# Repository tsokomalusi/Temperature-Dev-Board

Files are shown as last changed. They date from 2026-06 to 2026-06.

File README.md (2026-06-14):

# Project Requirements/Problem Statement
[Challenge](https://github.com/tsokomalusi/Temperature-Dev-Board/blob/main/%F0%9F%A7%A9%20Course%201%20%E2%80%94%20Temperature%20Monitor%20Dev%20Board%20-%20Course%201%20%E2%80%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)

# Temperature-Dev-Board

STM32-based temperature monitoring board featuring:

 10k NTC thermistor
- ADC temperature measurement
- OLED display
- USB power
- Expansion headers

## Hardware

- MCU: STM32
- Sensor: 10k NTC Thermistor
- Display: OLED
- 
## Schematic
The proposed schematic for this PCB Design challenge can be found within this repository
[Schematic](https://github.com/tsokomalusi/Temperature-Dev-Board/blob/main/Temperature_Monitoring_Dev_Board.pdf)

## Images

### BLOCK DIAGRAM
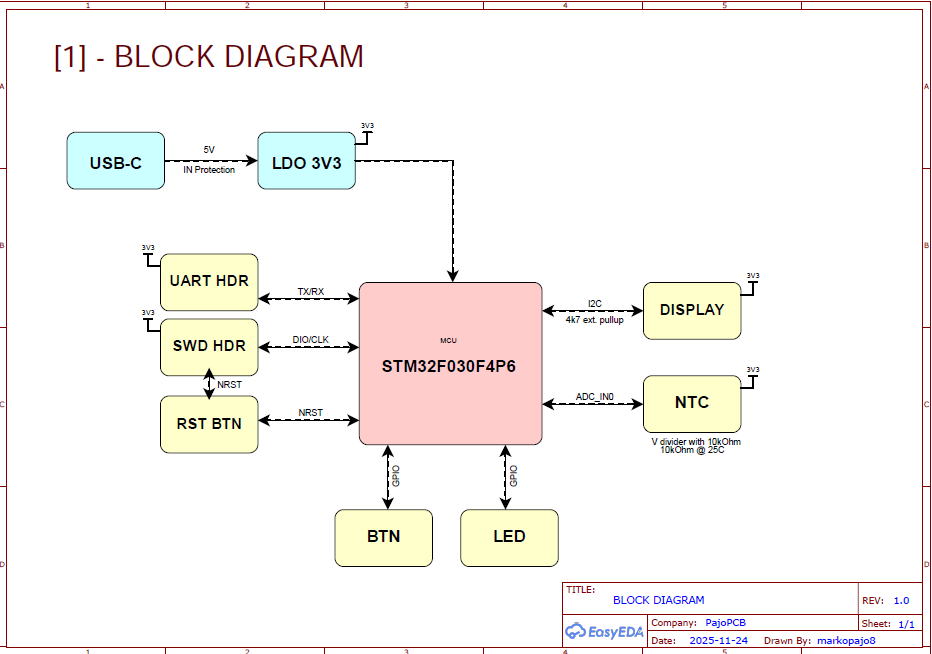
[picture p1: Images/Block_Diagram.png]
Block Diagram


### 3D MODEL (TOP & BOTTOM VIEW)

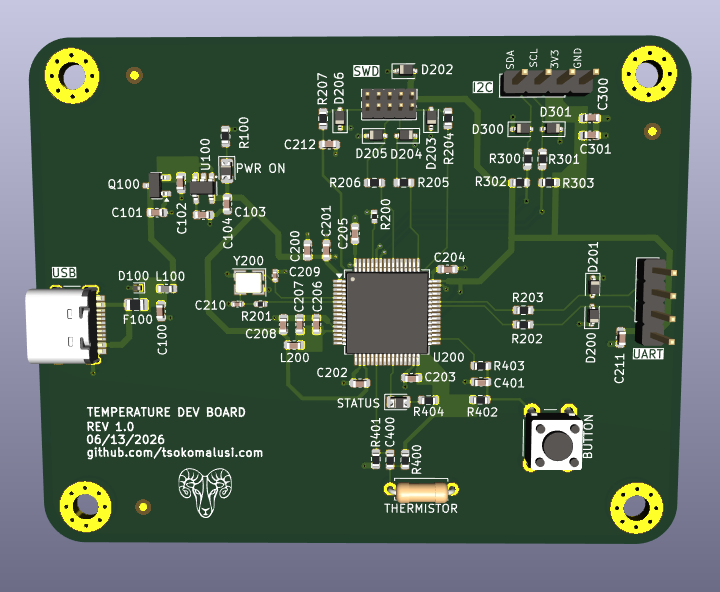
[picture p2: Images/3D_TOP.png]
3D TOP


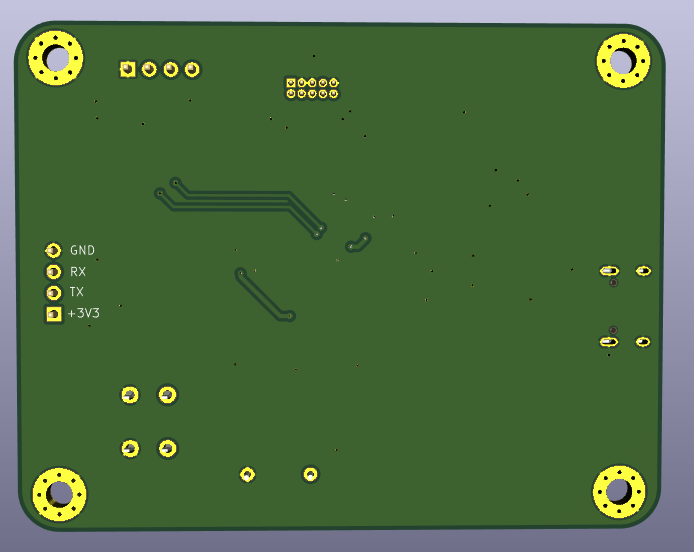
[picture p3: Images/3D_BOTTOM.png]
3D BOTTOM


### PCB LAYER (2 LAYER)

PCB STACKUP (2 LAYER)

L1: Signal/POWER
L2: GND

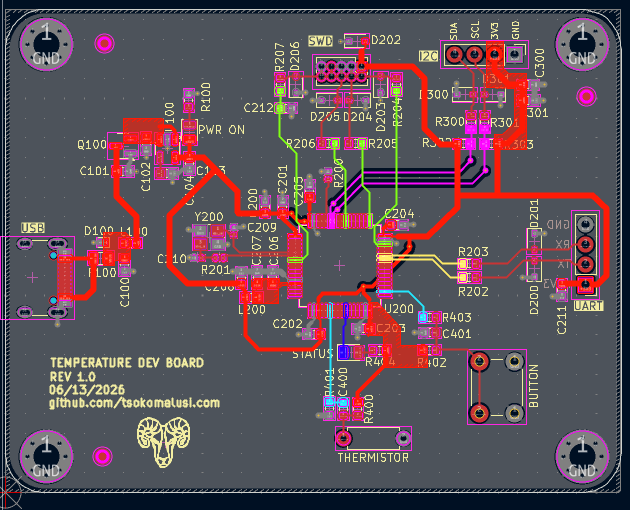
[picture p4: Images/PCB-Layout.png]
PCB_Layout


## Manufacturing

Gerber files are located in the manufacturing folder.

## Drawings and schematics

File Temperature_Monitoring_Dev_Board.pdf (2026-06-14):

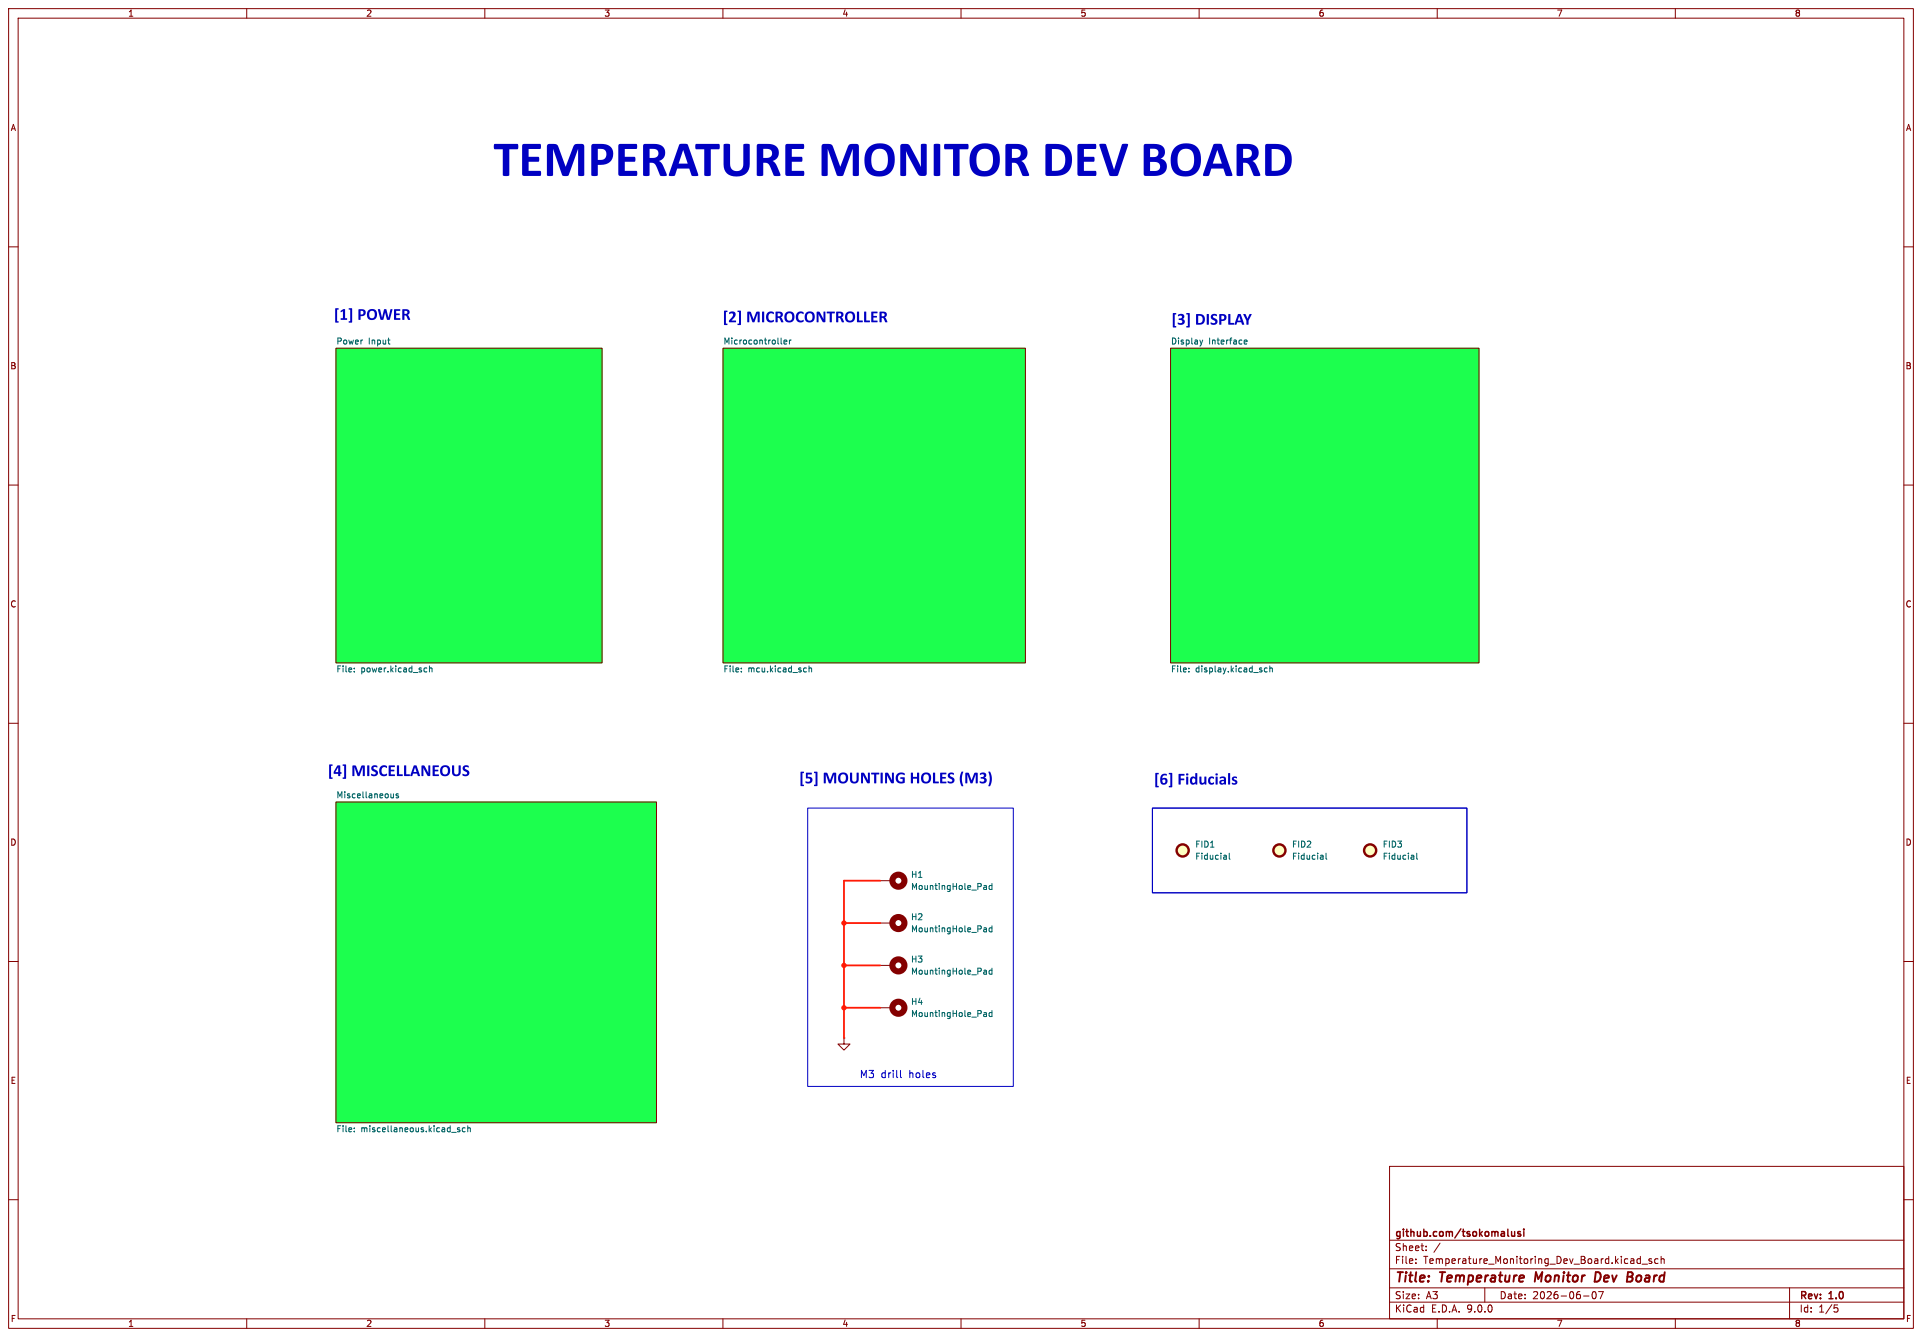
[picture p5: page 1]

Microcontroller File: mcu.kicad_sch Power Input File: power.kicad_sch

File: Temperature_Monitoring_Dev_Board.kicad_sch Sheet: / github.com/tsokomalusi Miscellaneous File: miscellaneous.kicad_sch

Id: 1/5 Title: Temperature Monitor Dev Board

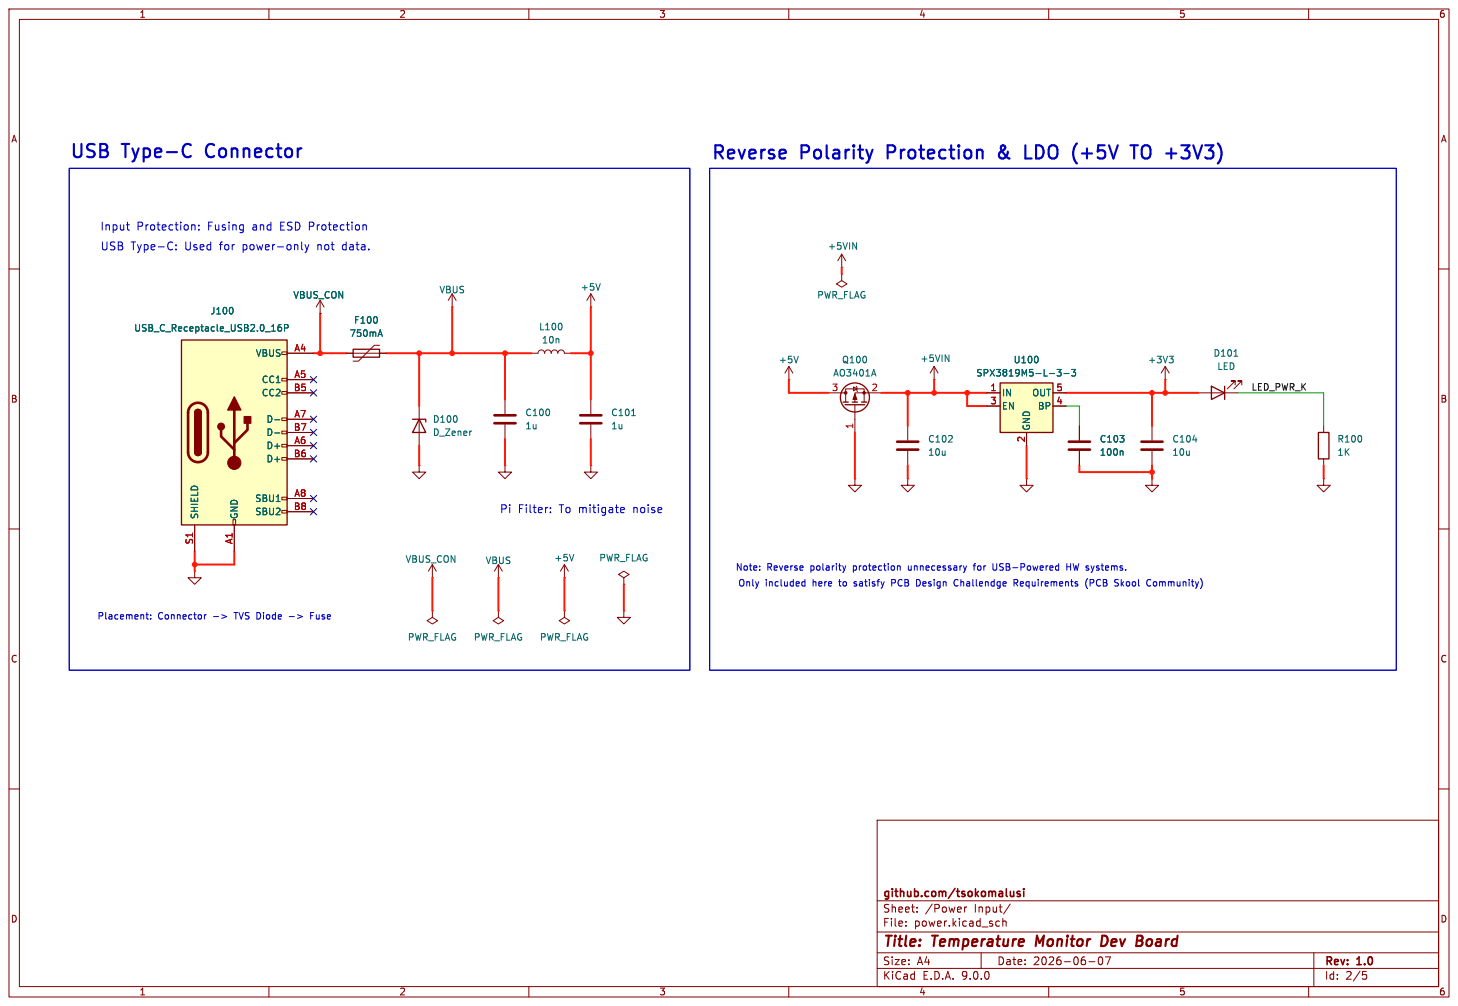
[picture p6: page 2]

Reverse Polarity Protection & LDO (+5V TO +3V3)

Id: 2/5 Title: Temperature Monitor Dev Board

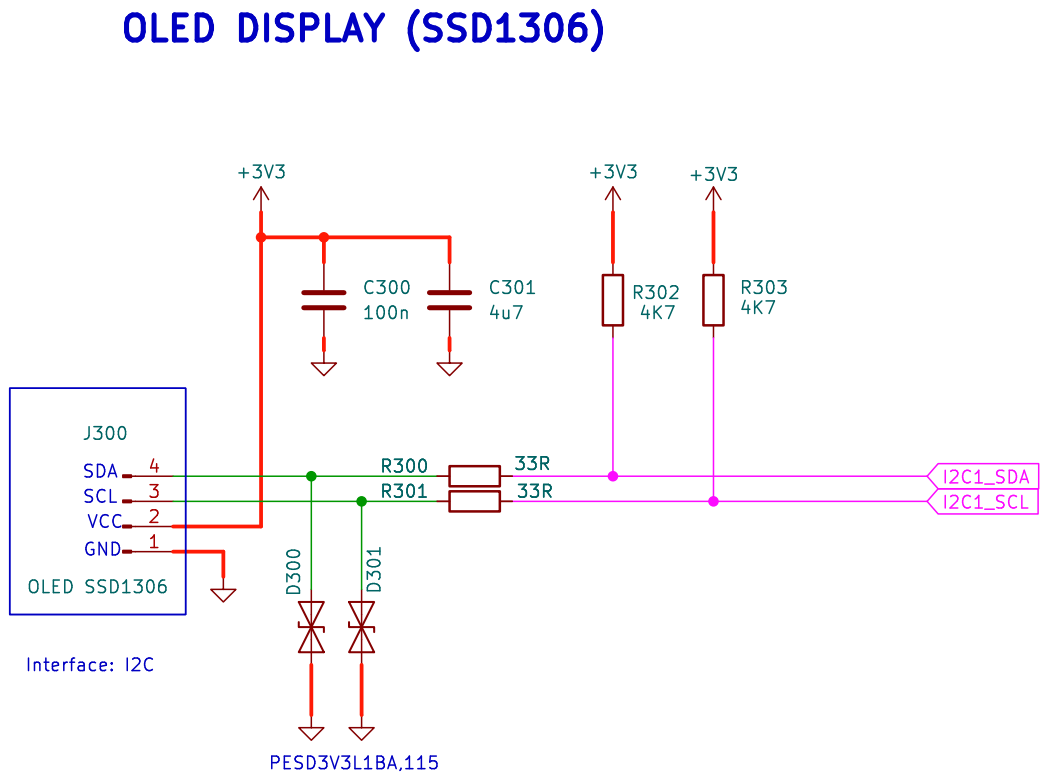
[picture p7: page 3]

Id: 3/5 Title: Temperature Monitor Dev Board

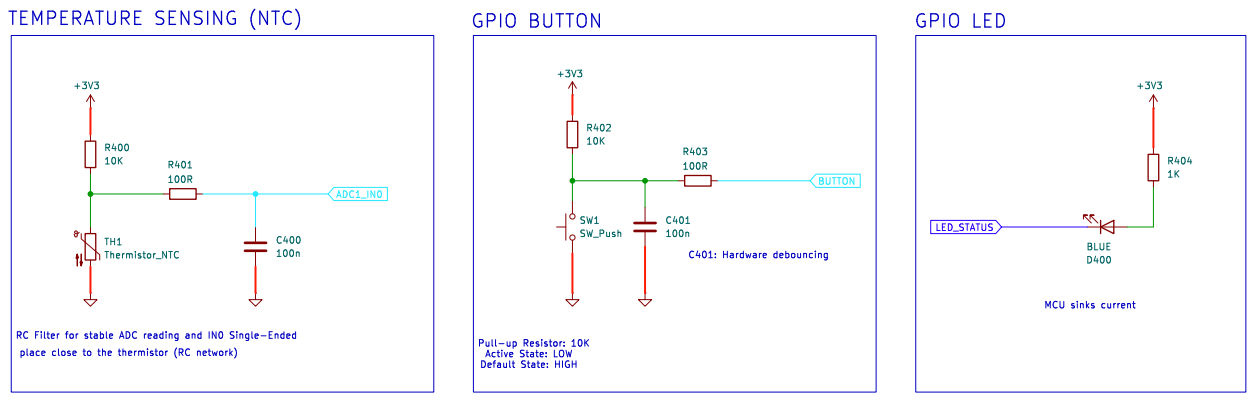
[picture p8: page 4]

File: miscellaneous.kicad_sch Sheet: /Miscellaneous/ github.com/tsokomalusi

Id: 5/5 Title: Temperature Monitor Dev Board

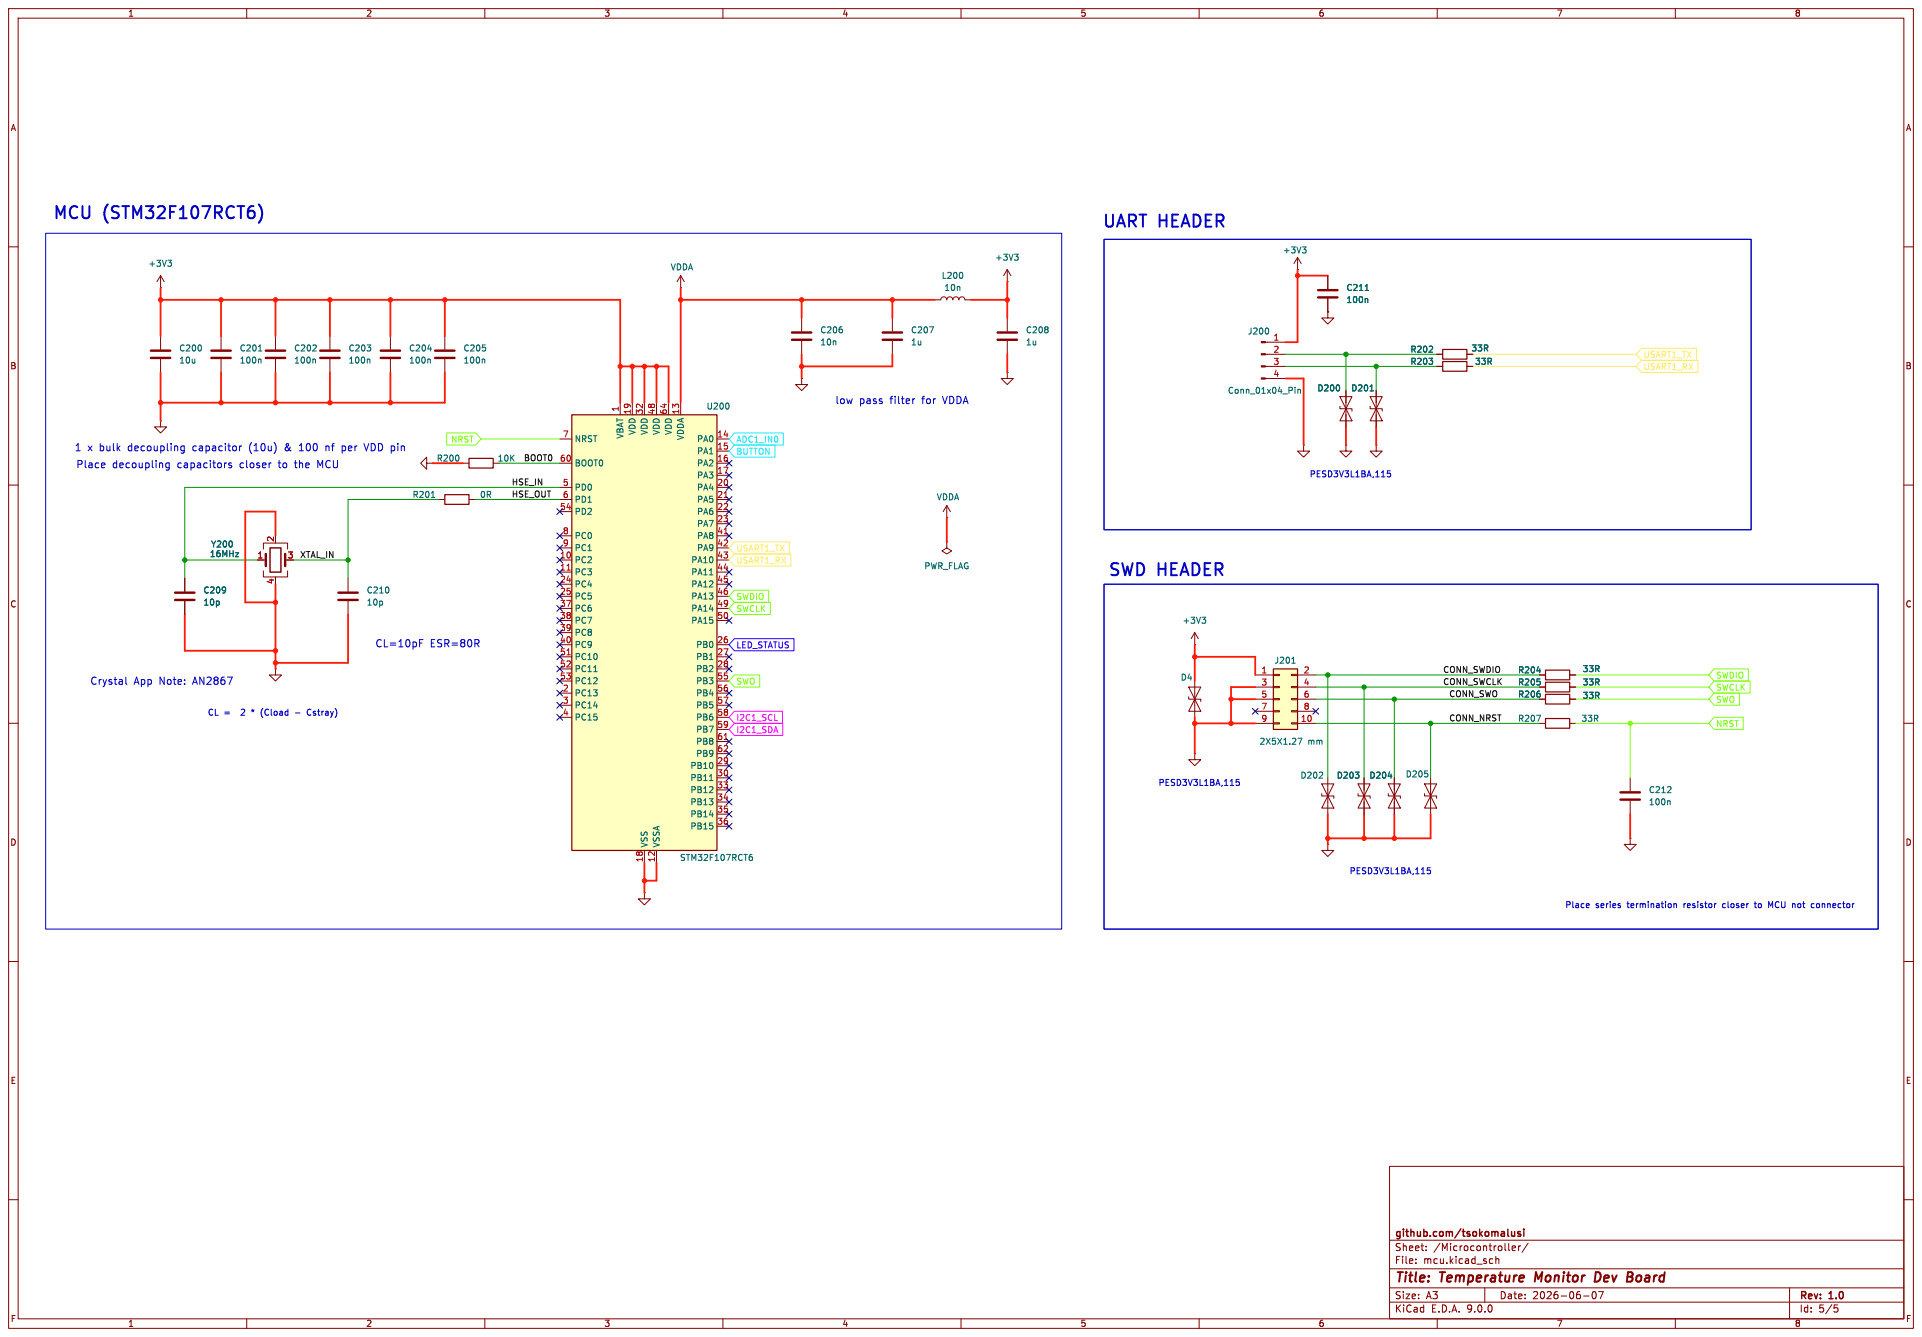
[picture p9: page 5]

low pass filter for VDDA CL=10pF ESR=80R

1 VDD 19 VDD 32 VSS 18 VDD 48 VSSA 12 VDD 64 VDDA 13 PA0 14 PA1 15 PA2 16 PA3 17 PA4 20 PA5 21 PA6 22 PA7 23 PA8 41 PA9 42 PA10 43 PA11 44 PA12 45 PA13 46 PA14 49 PA15 50 PB0 26 PB1 27 PB2 28 PB3 55 PB4 56 PB5 57 PB6 58 PB7 59 PB8 61 PB9 62 PB10 29 PB11 30 PB12 33 PB13 34 PB14 35 PB15 36 U200 STM32F107RCT6

File: mcu.kicad_sch Sheet: /Microcontroller/ github.com/tsokomalusi

Id: 5/5 Title: Temperature Monitor Dev Board

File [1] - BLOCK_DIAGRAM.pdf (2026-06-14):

USB-C | LDO 3V3

# [1] - BLOCK DIAGRAM

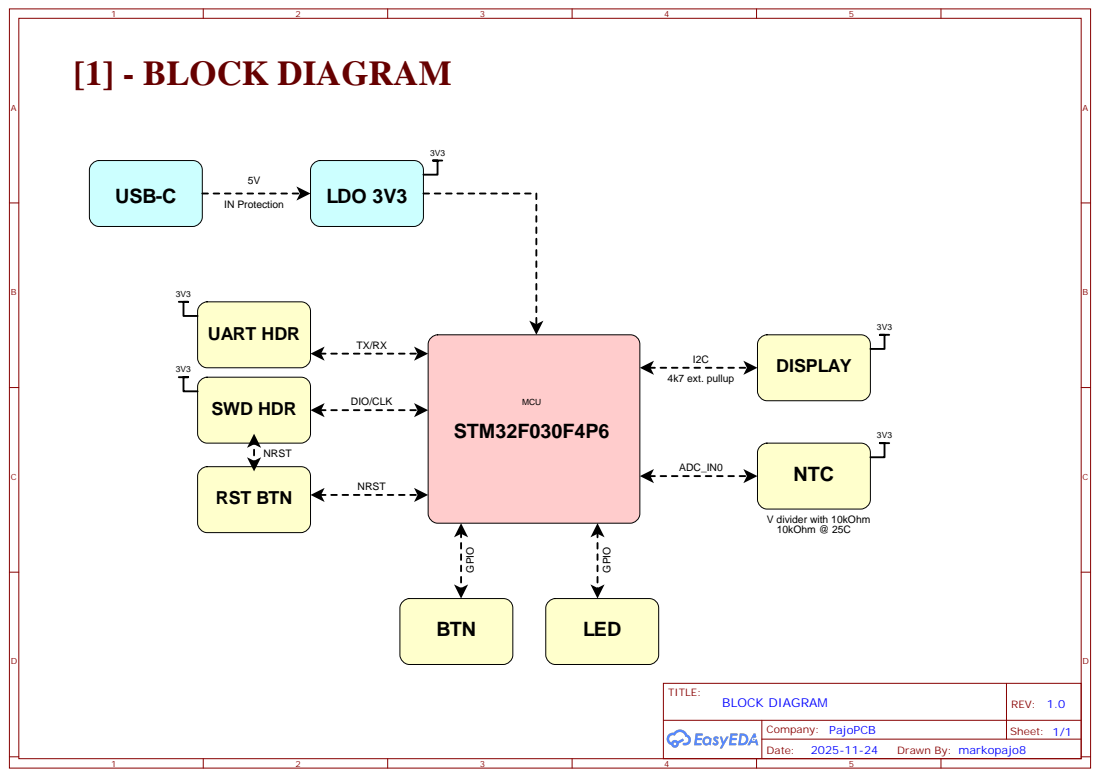
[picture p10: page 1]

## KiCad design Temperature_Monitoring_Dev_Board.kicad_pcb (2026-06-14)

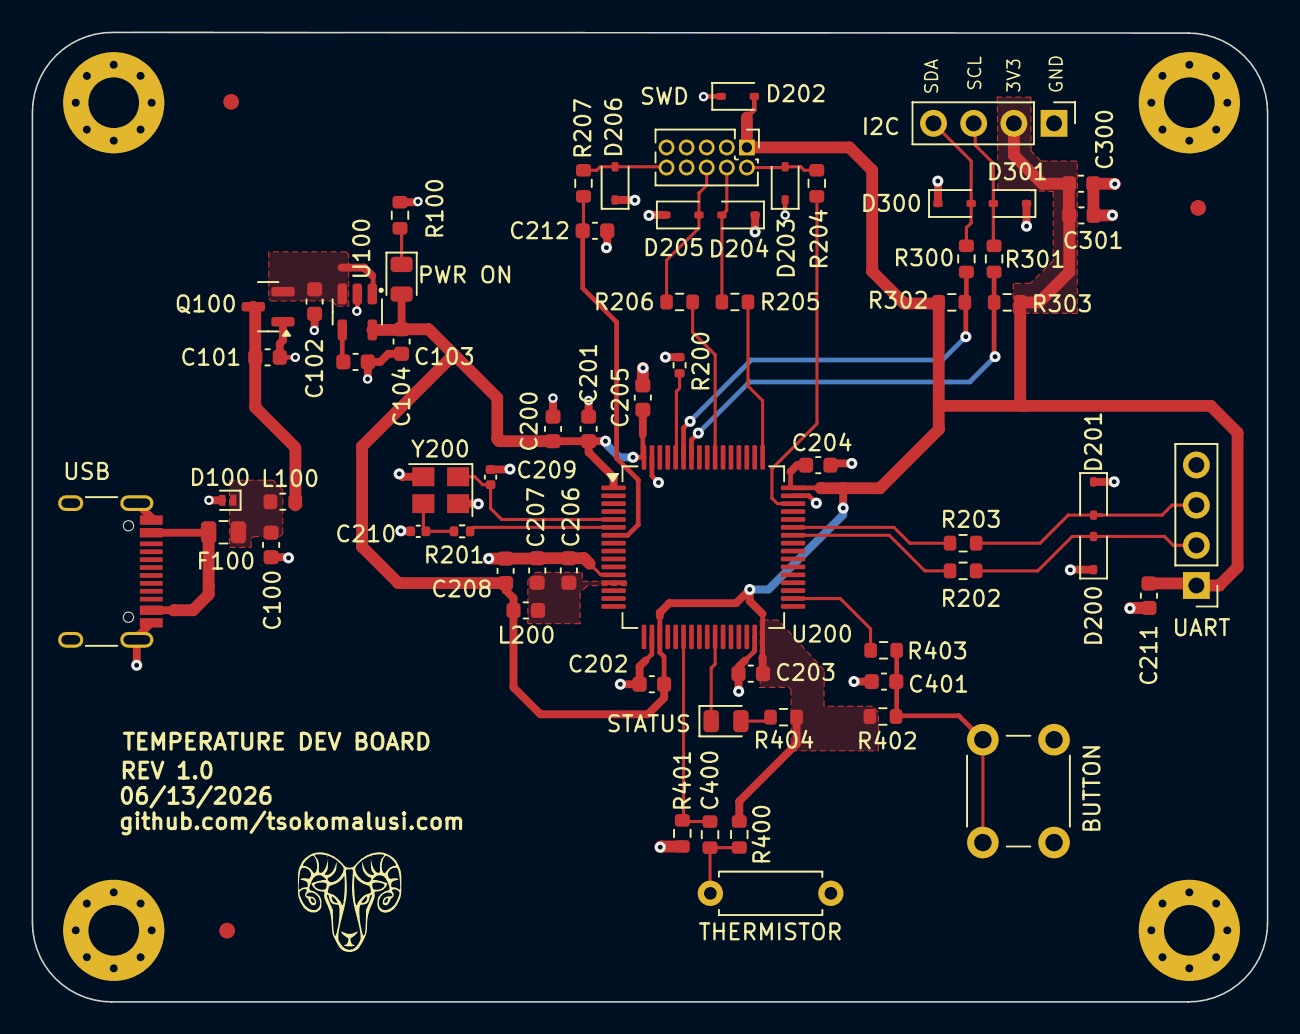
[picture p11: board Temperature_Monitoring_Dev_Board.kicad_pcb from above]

Board: 2 copper layers, 78.1 x 61.3 mm, 73 parts (0 on the bottom side), 35 nets.

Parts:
BUTTON: SW_Push; SW_PUSH_6mm
C100, C101, C207, C208: 1u; C_0603_1608Metric
C102, C104, C200: 10u; C_0603_1608Metric
C103, C201, C202, C203, C204, C205, C211, C212, C300, C401: 100n; C_0603_1608Metric
C206: 10n; C_0603_1608Metric
C209, C210: 10p; C_0402_1005Metric
C301: 4u7; C_0603_1608Metric
C400: 100n; R_0603_1608Metric
D100: D_Zener; D_SOD-882
D200, D201, D202, D203, D204, D205, D206, D300, D301: PESD3V3L1BA,115; D_SOD-323
F100: 750mA; Fuse_0805_2012Metric
FID1, FID2, FID3: Fiducial; Fiducial_1mm_Mask2mm
H1, H2, H3, H4: MountingHole_Pad; MountingHole_3.2mm_M3_Pad_Via
I2C: OLED SSD1306; PinHeader_1x04_P2.54mm_Vertical
L100: 10n; L_0603_1608Metric
L200: 10n; C_0603_1608Metric
PWR ON: LED; D_0805_2012Metric
Q100: AO3401A; SOT-23
R100, R404: 1K; R_0603_1608Metric
R200: 10K; R_0402_1005Metric
R201: 0R; R_0402_1005Metric
R202, R203, R204, R205, R206, R207, R300, R301: 33R; R_0603_1608Metric
R302, R303: 4K7; R_0603_1608Metric
R400, R402: 10K; R_0603_1608Metric
R401, R403: 100R; R_0603_1608Metric
STATUS: BLUE; D_0805_2012Metric
SWD: 2X5X1.27 mm; PinHeader_2x05_P1.27mm_Vertical
THERMISTOR: Thermistor_NTC; R_Axial_DIN0207_L6.3mm_D2.5mm_P7.62mm_Horizontal
U100: SPX3819M5-L-3-3; SOT-23-5
U200: STM32F107RCT6; LQFP-64_10x10mm_P0.5mm
UART: Conn_01x04_Pin; PinHeader_1x04_P2.54mm_Vertical
USB: USB_C_Receptacle_USB2.0_16P; USB_C_Receptacle_HRO_TYPE-C-31-M-12
Xigote_Log: LOGO; Footprint_logos
Y200: 16MHz; Crystal_SMD_3225-4Pin_3.2x2.5mm

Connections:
+3V3: C104.1, C200.1, C201.1, C202.1, C203.1, C204.1, C205.1, C208.1, C211.1, C300.1, C301.1, D202.2 (A2), I2C.2, L200.2, PWR ON.2 (A), R302.1, R303.1, R400.1, R402.1, R404.1, SWD.1, U100.5 (OUT), U200.1 (VBAT), U200.19 (VDD), U200.32 (VDD), U200.48 (VDD), U200.64 (VDD), UART.1
+5V: C101.1, L100.2, Q100.3 (D)
+5VIN: C102.1, Q100.2 (S), U100.1 (IN), U100.3 (EN)
/Microcontroller/BOOT0: R200.2, U200.60 (BOOT0)
/Microcontroller/CONN_NRST: D206.2 (A2), R207.1, SWD.10
/Microcontroller/CONN_SWCLK: D204.2 (A2), R205.1, SWD.4
/Microcontroller/CONN_SWDIO: D203.2 (A2), R204.1, SWD.2
/Microcontroller/CONN_SWO: D205.2 (A2), R206.1, SWD.6
/Microcontroller/HSE_IN: C209.1, U200.5 (PD0), Y200.1
/Microcontroller/HSE_OUT: R201.2, U200.6 (PD1)
/Microcontroller/XTAL_IN: C210.1, R201.1, Y200.3
/Power Input/LED_PWR_K: PWR ON.1 (K), R100.1
ADC1_IN6: C400.1, R401.2, U200.22 (PA6)
BUTTON: R403.2, U200.34 (PB13)
GND: BUTTON.1, C100.2, C101.2, C102.2, C103.2, C104.2, C200.2, C201.2, C202.2, C203.2, C204.2, C205.2, C206.2, C207.2, C208.2, C209.2, C210.2, C211.2, C212.2, C300.2, C301.2, C400.2, C401.2, D100.2 (A), D200.1 (A1), D201.1 (A1), D202.1 (A1), D203.1 (A1), D204.1 (A1), D205.1 (A1), D206.1 (A1), D300.1 (A1), D301.1 (A1), H1.1, H2.1, H3.1, H4.1, I2C.1, Q100.1 (G), R100.2, R200.1, SWD.3, SWD.5, SWD.9, THERMISTOR.2, U100.2 (GND), U200.12 (VSSA), U200.18 (VSS), U200.31 (VSS), U200.47 (VSS), U200.63 (VSS), UART.4, USB.A1 (GND), USB.A12 (GND), USB.B1 (GND), USB.B12 (GND), USB.S1 (SHIELD), Y200.2, Y200.4
I2C1_SCL: R301.2, R303.2, U200.58 (PB6)
I2C1_SDA: R300.2, R302.2, U200.59 (PB7)
LED_STATUS: STATUS.1 (K), U200.26 (PB0)
NRST: C212.1, R207.2, U200.7 (NRST)
unnamed: BUTTON.2, C401.1, R402.2, R403.1
unnamed: D200.2 (A2), R202.1, UART.2
unnamed: D201.2 (A2), R203.1, UART.3
unnamed: D300.2 (A2), I2C.4, R300.1
unnamed: D301.2 (A2), I2C.3, R301.1
unnamed: R404.2, STATUS.2 (A)
unnamed: R400.2, R401.1, THERMISTOR.1
unnamed: C103.1, U100.4 (BP)
SWCLK: R205.2, U200.49 (PA14)
SWDIO: R204.2, U200.46 (PA13)
SWO: R206.2, U200.55 (PB3)
USART1_RX: R203.2, U200.43 (PA10)
USART1_TX: R202.2, U200.42 (PA9)
VBUS: C100.1, D100.1 (K), F100.2, L100.1
VBUS_CON: F100.1, USB.A4 (VBUS), USB.A9 (VBUS), USB.B4 (VBUS), USB.B9 (VBUS)
VDDA: C206.1, C207.1, L200.1, U200.13 (VDDA)
